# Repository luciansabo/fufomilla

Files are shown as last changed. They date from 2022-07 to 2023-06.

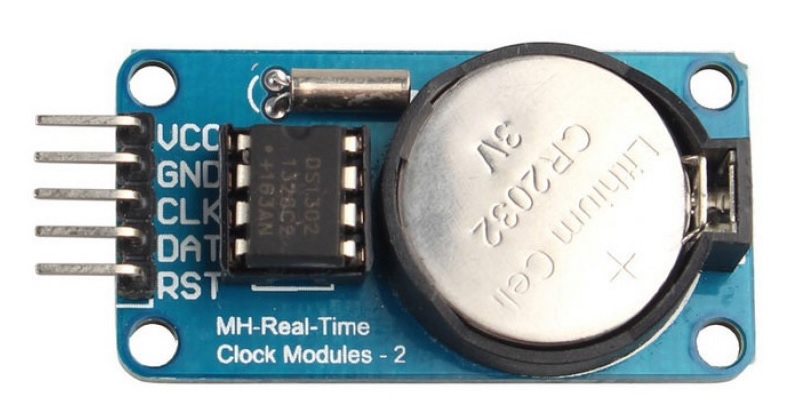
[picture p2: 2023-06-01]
docs/DS1302-RTC-mdule-pinout-diagram.jpg

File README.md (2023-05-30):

## Fufomilla

Automated Cat/Dog/Pet Feeder

*Created for ESP32/ESP32 CAM, but should work with minimal changes with other boards*

### Features
- based on a popular manual cereal dispenser + 3d printed parts 
- Wifi control/monitoring and automatic reconnects
- configuration portal (Wifi manager) on double reset
- supports ESP32 CAM (tested on the AI Thinker version) with 3 simultaneous camera streams and 20 fps, should work on any ESP32 though
- MQTT communication (can be easily integrated with Home Assistant) with integrated sensors like status, food level, remaining portions
- supports an optional ultrasonic food level sensor
- scheduled feeding based on NTP time and optionally a real time clock module
- manual feeding possible through MQTT a command

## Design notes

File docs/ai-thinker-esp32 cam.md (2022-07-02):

## INTRODUCTION TO AL-CAM THINKER

Source: https://www.electrorules.com/esp32-cam-ai-thinker-pinout-guide-gpios-usage-explained/

For quite some time, the world has revolved around IoTs, or Internet of Things. Everyone is interested in Smart technology, from enthusiasts to innovators, in building various prototypes and goods, and launching them on the market. One of the most common clever modules for IoTs is the ESP32 Series processor. Espressif’s ESP32-CAM AI-Thinker is an enhanced version of the ESP8266-01 with numerous functionalities. Two high-performance 32-bit LX6 CPUs with a 7-stage pipeline architecture are included in the ultra-small, low-power module.

## Applications
ESP32-CAM AI-Thinker module has a never-ending list of applications like home automation, intelligent devices, positioning systems, security systems and perfect for IoT applications.

## POWER PINS
The ESP32-CAM has three GND pins (coloured black) and two power pins (coloured red): 3.3V and 5V, respectively.

The ESP32-CAM can be powered from the 3.3V or 5V pins. However, many individuals have noticed issues while using 3.3V to power the ESP32-CAM, thus we always recommend using the 5V pin.

## POWER OUTPUT PIN
There’s also the VCC pin, which is labelled on the silkscreen (colored with a yellow rectangle). That pin should not be used to power the ESP32-CAM. That is a power output pin. It may produce either 5V or 3.3V.

Whether supplied with 5V or 3.3V, the ESP32-CAM outputs 3.3V in our situation. Two pads are located next to the VCC pin. One is labelled 3.3V and the other is labelled 5V.

## SERIAL PIN
GPIO 1 and GPIO 3 are the serial pins (TX and RX, respectively). Because the ESP32-CAM doesn’t have a built-in programmer, you need to use these pins to communicate with the board and upload code.

You can use GPIO 1 and GPIO 3 to connect other peripherals like outputs or sensors after uploading the code. However, you won’t be able to open the Serial Monitor and see if everything is going well with your setup.

GPIO 0
GPIO 0 determines whether the ESP32 is in flashing mode or not. This GPIO is internally connected to a pull-up 10k Ohm resistor.

When GPIO 0 is connected to GND, the ESP32 goes into flashing mode and you can upload code to the board.

GPIO 0 connected to GND » ESP32-CAM in flashing mode
To make the ESP32 run “normally”, you just need to disconnect GPIO 0 from GND.

## MICROSD CONNECTION
The following pins are used to interface with the microSD card when it is on operation.

Microsd card	ESP32
CLK	GPIO 14
CMD	GPIO15
DATA0	GPIO 2
DATA 1/flashlight	GPIO 4
DATA2	GPIO 12
DATA3	GPIO13

## FLASHLIGHT(GPIO4)
The ESP32-CAM has a very bright built-in LED that can work as a flash when taking

photos. That LED is internally connected to GPIO 4.

That GPIO is also connected to the microSD card slot, so you may have troubles when trying to use both at the same time – the flashlight will light up when using the microSD card.

## GPIO 33 – BUILT- IN RED LIGHT
An on-board red LED is located next to the RST button. Internally, its LED is coupled to GPIO 33. This LED can be used to signal that something is happening. When Wi-Fi is enabled, for example, the LED turns red, and vice versa.

That LED uses inverted logic, thus to turn it on, send a LOW signal, and to turn it off, provide a HIGH signal.

```
void setup() {

  pinMode(33, OUTPUT);

}

void loop() {

  digitalWrite(33, LOW);

}
```

## CAMERA CONNECTIONS
The connections between the camera and the ESP32-CAM AI-Thinker are shown in the following table.

OV2640 CAMERA	ESP32	Variable name in code
DO	GPIO 5	Y2_GPIO_NUM
D1	GPIO 18	Y3_GPIO_NUM
D2	GPIO 19	Y4_GPIO_NUM
D3	GPIO 21	Y5_GPIO_NUM
D4	GPIO 36	Y6_GPIO_NUM
D5	GPIO 39	Y7_GPIO_NUM
D6	GPIO 34	Y8_GPIO_NUM
D7	GPIO 35	Y9_GPIO_NUM
XCLK	GPIO 0	XCLK_GPIO_NUM
PCLK	GPIO 22	PCLK_GPIO_NUM
VSYNC	GPIO 25	VSYNC_GPIO_NUM
HREF	GPIO 23	HREF_GPIO_NUM
SDA	GPIO 26	SIOD_GPIO_NUM
SCL	GPIO 27	SIOC_GPIO_NUM
POWERPIN	GPIO 32	PWDN_GPIO_NUM

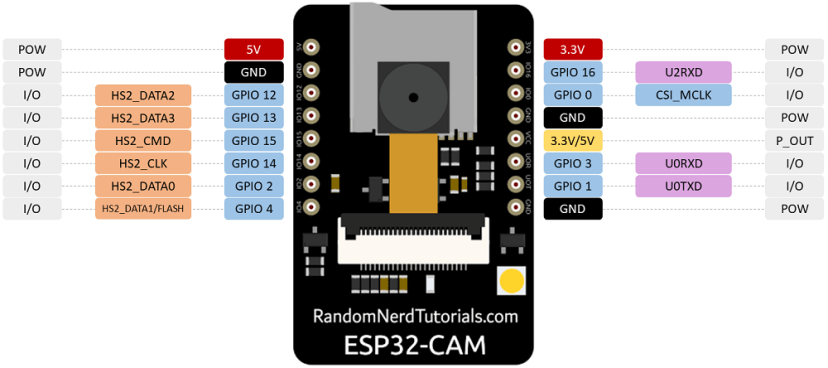
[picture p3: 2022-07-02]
docs/ESP32-CAM-pinout.png

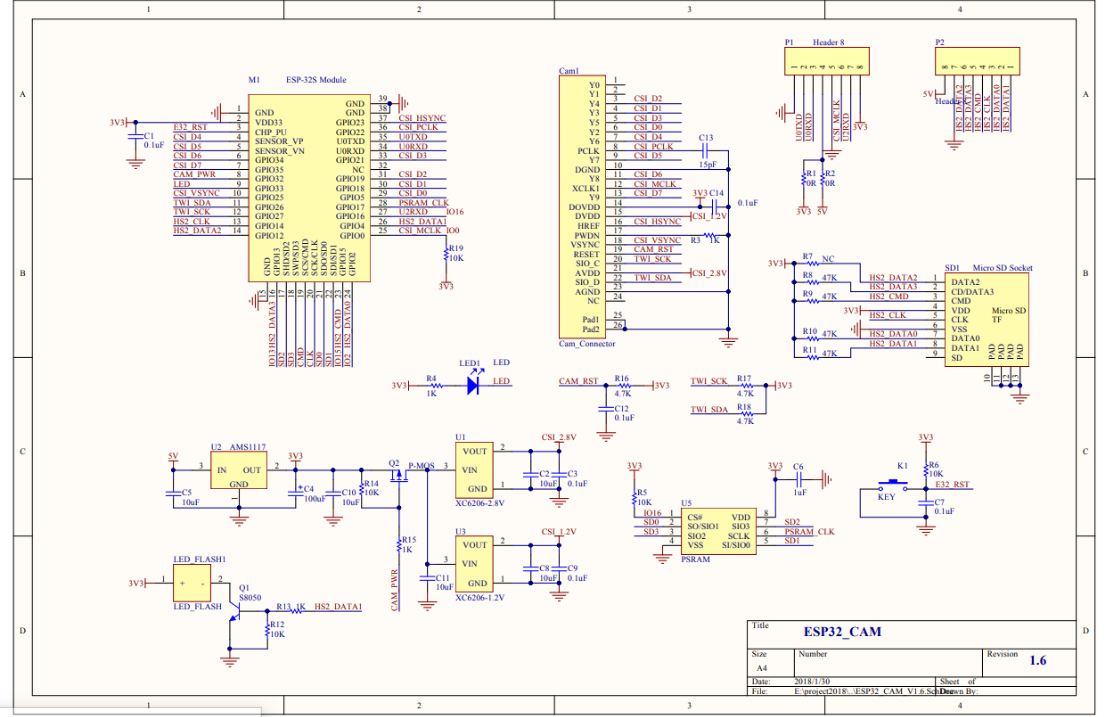
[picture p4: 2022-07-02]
docs/ESP32-CAM-circuit-diagram.PNG

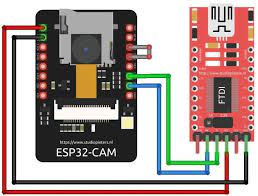
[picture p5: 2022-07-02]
docs/ftdi-connections.jpeg

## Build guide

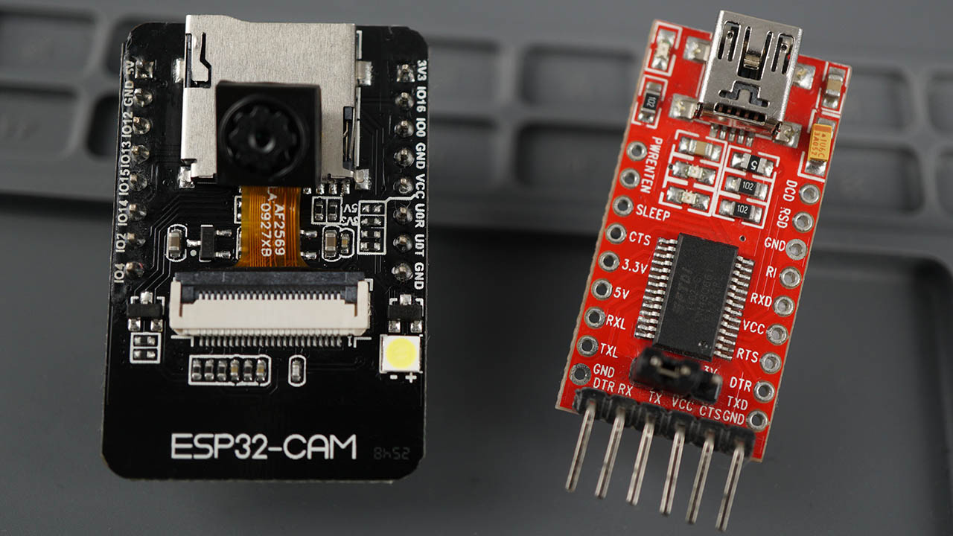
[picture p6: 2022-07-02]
docs/how-to-program-upload-code-firmware-ESP32-CAM-board-Arduino-IDE-FTDI.jpg

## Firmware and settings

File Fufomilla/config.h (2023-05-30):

#define HAS_FOOD_LEVEL_SENSOR 1
#define HAS_RTC               1
#define HAS_CAMERA            1

// Pins
#define PIN_SERVO 13
#define PIN_BRIGHT_LED 4
#define PIN_BUILTIN_LED 33

#define PIN_RTC_DAT        2
#define PIN_RTC_CLK       16
#define PIN_RTC_RST       12

#define PIN_HCSR04_TRIG 14
#define PIN_HCSR04_ECHO 15


// Timing
#define DEFAULT_JERK_TIME 1 * 1000 // controls portion. Time in ms to rotate left/right
#define WIFI_WATCHDOG_INTERVAL  (5 * 60 * 1000) // 5m
#define MQTT_WATCHDOG_INTERVAL  (60 * 1000) // 1m
#define MQTT_HANDLING_INTERVAL  (1 * 1000) // 1s
#define MQTT_KEEP_ALIVE_SEC     60 // 60s
#define FOOD_LEVEL_READING_INTERVAL (3600 * 1000) // 1h
#define RTC_SYNC_INTERVAL_WITH_NTC (4 * 60 * 1000) // every 4h

// Config portal
#define CONFIG_PORTAL_AP_NAME   "Fufomilla"
#define CONFIG_PORTAL_AP_PASS   ""
#define CONFIG_PORTAL_TIMEOUT_SEC (10 * 60) // 10 min

// wifi
#define HOSTNAME                "Fufomilla"
#define WIFI_CONNECT_TIMEOUT_SEC 40 // 40s

// Number of seconds after reset during which a
// subseqent reset will be considered a double reset.
#define DRD_TIMEOUT 10

// RTC Memory Address for the DoubleResetDetector to use
#define DRD_ADDRESS 0

// ID of the settings block
#define CONFIG_VERSION "FM1"

// Tell it where to store your config data in EEPROM
#define CONFIG_START_ADDR 0

// Time
#define TIME_TZ                "EET-2EEST,M3.5.0/3,M10.5.0/4"
#define TIME_NTP_SERVER        "pool.ntp.org"

// MQTT
#define DEFAULT_MQTT_BROKER   "home-assistant.local"
#define DEFAULT_MQTT_PORT     "1883"
#define DEFAULT_MQTT_USERNAME "homeassistant"
#define DEFAULT_MQTT_PASSWORD ""
#define TOPIC_COMMAND_FEED_ME "saboiot/fufomilla/commands/feed"
#define TOPIC_COMMAND_SWITCH_LED      "saboiot/fufomilla/commands/led"
#define TOPIC_EVENTS          "saboiot/fufomilla/events"
#define TOPIC_FOOD_LEVEL      "saboiot/fufomilla/food-level"
#define TOPIC_LED    "saboiot/fufomilla/led"
#define TOPIC_AVAILABILITY    "saboiot/fufomilla/availability"

#define FOOD_CONTAINER_HEIGHT_CM 20
#define FOOD_CONTAINER_PORTIONS 36

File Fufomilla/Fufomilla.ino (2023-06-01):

/*
   Fufomilla - cat feeder
   Board: ESP32 Dev module
   Minimal SPIFFS
   PSRAM Disabled -> incompatible with DS1302 RTC module
   Arduino run on Core 1, events on Core 0
*/

#include <ESP32Servo.h>
#include <WiFiManager.h>
#include <PubSubClient.h>  // MQTT Client
#include <ArduinoOTA.h>
#include <ESPmDNS.h>
#include <time.h>
#include <CronAlarms.h>
#include <SimpleTimer.h>  // https://playground.arduino.cc/Code/SimpleTimer/

// ESP32 needs EEPROM
#if defined(ESP32)
#define USE_SPIFFS true
#define ESP_DRD_USE_EEPROM true
#else
#error This code is intended to run on the ESP32 platform! Please check your Tools->Board setting.
#endif
#include <ESP_DoubleResetDetector.h>  //https://github.com/khoih-prog/ESP_DoubleResetDetector

// app config
#include "config.h"
#include "config.local.h"

#ifdef HAS_FOOD_LEVEL_SENSOR
#include <HCSR04.h>
UltraSonicDistanceSensor distanceSensor(PIN_HCSR04_TRIG, PIN_HCSR04_ECHO);
#endif

#ifdef HAS_RTC
#include <ThreeWire.h>
#include <RtcDS1302.h>

ThreeWire threeWire(PIN_RTC_DAT, PIN_RTC_CLK, PIN_RTC_RST);  // IO, SCLK, CE
RtcDS1302<ThreeWire> rtc(threeWire);
#endif

DoubleResetDetector* drd;

// network
WiFiClient espClient;
unsigned long wifiReconnectTime = 0;
// servers
PubSubClient mqtt(espClient);

bool isManualDispense = false;

#ifdef HAS_CAMERA
#include "Esp32CamAsyncWebserver.h"
camera_config_t esp32cam_aithinker_config{

  .pin_pwdn = 32,
  .pin_reset = -1,

  .pin_xclk = 0,

  .pin_sscb_sda = 26,
  .pin_sscb_scl = 27,

  // Note: LED GPIO is apparently 4 not sure where that goes
  // per https://github.com/donny681/ESP32_CAMERA_QR/blob/e4ef44549876457cd841f33a0892c82a71f35358/main/led.c
  .pin_d7 = 35,
  .pin_d6 = 34,
  .pin_d5 = 39,
  .pin_d4 = 36,
  .pin_d3 = 21,
  .pin_d2 = 19,
  .pin_d1 = 18,
  .pin_d0 = 5,
  .pin_vsync = 25,
  .pin_href = 23,
  .pin_pclk = 22,
  .xclk_freq_hz = 20000000,  // faster fps
  .ledc_timer = LEDC_TIMER_1,
  .ledc_channel = LEDC_CHANNEL_1,
  .pixel_format = PIXFORMAT_JPEG,
  // .frame_size = FRAMESIZE_UXGA, // needs 234K of framebuffer space
  // .frame_size = FRAMESIZE_SXGA, // needs 160K for framebuffer
  // .frame_size = FRAMESIZE_XGA, // needs 96K or even smaller FRAMESIZE_SVGA - can work if using only 1 fb
  .frame_size = FRAMESIZE_QVGA,      // 240x176
  .jpeg_quality = 15,                //0-63 lower numbers are higher quality
  .fb_count = 1,                     // if more than one i2s runs in continous mode.  Use only with jpeg
  .fb_location = CAMERA_FB_IN_DRAM,  // disable PSRAM
  .grab_mode = CAMERA_GRAB_WHEN_EMPTY
};

Esp32CamWebserver camServer;
#endif

// software timer
SimpleTimer simpleTimer;

// MQTT Broker
struct MqttConfigStruct {
  char configVersion[5] = CONFIG_VERSION;
  char broker[100] = DEFAULT_MQTT_BROKER;
  char port[5] = DEFAULT_MQTT_PORT;
  char username[30] = DEFAULT_MQTT_USERNAME;
  char password[100] = DEFAULT_MQTT_PASSWORD;
  uint16_t jerkTime = DEFAULT_JERK_TIME;
} mqttConfig;

// Wifimanager variables
WiFiManager wifiManager;
WiFiManagerParameter paramMqttBroker("mqttBroker", "MQTT broker", mqttConfig.broker, 40);
WiFiManagerParameter paramMqttPort("mqttPort", "MQTT port", mqttConfig.port, 10);
WiFiManagerParameter paramMqttUsername("mqttUser", "MQTT user", mqttConfig.username, 40);
WiFiManagerParameter paramMqttPassword("mqttPassword", "MQTT password", mqttConfig.password, 40);

Servo myservo;  // create servo object to control a servo
// 16 servo objects can be created on the ESP32

struct TStats {
  time_t upSince;
  char lastOperation[100];
} stats;

// ------------------------------------------------------------------------------------------

void setupOTA() {
  ArduinoOTA.setHostname(HOSTNAME);
  ArduinoOTA.begin();
  ArduinoOTA.onStart([]() {
    log_i("OTA firmware update started");
    //hwTimer.disableTimer();
  });
  ArduinoOTA.onEnd([]() {
    log_i("OTA Updated completed");
    // hwTimer.enableTimer();
  });
  ArduinoOTA.onError([](ota_error_t error) {
    //hwTimer.enableTimer();
    log_e("Error[%u]: ", error);
    if (error == OTA_AUTH_ERROR) {
      log_e("Auth Failed");
    } else if (error == OTA_BEGIN_ERROR) {
      log_e("Begin Failed");
    } else if (error == OTA_CONNECT_ERROR) {
      log_e("Connect Failed");
    } else if (error == OTA_RECEIVE_ERROR) {
      log_e("Receive Failed");
    } else if (error == OTA_END_ERROR) {
      log_e("End Failed");
    }
  });
}

// ------------------------------------------------------------------------------------------


void mqttPublish(const char* topic, const char* message, bool retain = false) {
  ensureMqttConnected();

  if (!mqtt.publish(topic, message, retain)) {
    log_e("MQTT Publish failed. Topic: %s\nMsg: %s\nState: %d", topic, message, mqtt.state());
  }
}

// ------------------------------------------------------------------------------------------

void ensureMqttConnected() {
  if (WiFi.status() != WL_CONNECTED) {
    return;
  }

  if (mqtt.connected()) {
    return;
  }

  log_i("Connecting to the mqtt broker... ");

  if (mqtt.connect(HOSTNAME, mqttConfig.username, mqttConfig.password, TOPIC_AVAILABILITY, 0, true, "{\"status\": \"offline\", \"upSince\": null}")) {
    log_i("Connected to MQTT");
    mqtt.subscribe(TOPIC_COMMAND_FEED_ME);
    mqtt.subscribe(TOPIC_COMMAND_SWITCH_LED);

    char message[200];
    //char timeBuf[sizeof "2011-10-08T07:07:09Z"];
    //strftime(timeBuf, sizeof timeBuf, "%FT%TZ", localtime(&stats.upSince));
    char timeBuf[sizeof "Joi, 30 Aug 2022 09:03"];
    strftime(timeBuf, sizeof timeBuf, "%a, %e %b %Y %R", localtime(&stats.upSince));
    sprintf(message, "{\"status\": \"online\",  \"upSince\": \"%s\"}", timeBuf);
    log_i("Publish availability message: %s", message);
    mqttPublish(TOPIC_AVAILABILITY, message, true);
  } else {
    log_e("failed with state %d", mqtt.state());
  }
}

// ------------------------------------------------------------------------------------------

void _dispenseMinPortion() {
  // try to fix issue with bright led that lits up
  digitalWrite(PIN_BRIGHT_LED, LOW);
  myservo.write(180);
  delay(DEFAULT_JERK_TIME);
  myservo.write(90);
  delay(200);
  myservo.write(0);
  delay(DEFAULT_JERK_TIME);
  myservo.write(90);
  digitalWrite(PIN_BRIGHT_LED, LOW);
}

// ------------------------------------------------------------------------------------------
/*void onDispenseStart() {
  
}*/

// ------------------------------------------------------------------------------------------

void onDispenseCompleted() {
  char message[200];
  char timeBuf[sizeof "Joi, 30 Aug 2022 09:03"];
  struct tm timeinfo;

  getLocalTime(&timeinfo);

  strftime(timeBuf, sizeof timeBuf, "%R %e %b", &timeinfo);
  sprintf(message, "{\"event\": \"%s %s\"}",
          isManualDispense ? "Manual feeding at" : "Scheduled feeding at",
          timeBuf);
  mqttPublish(TOPIC_EVENTS, message, true);

#ifdef HAS_FOOD_LEVEL_SENSOR
  readFoodLevel();
#endif
}

// ------------------------------------------------------------------------------------------

void dispense() {
  //onDispenseStart();
  log_i("Scheduled dispense");
  _dispenseMinPortion();
  onDispenseCompleted();
}

// ------------------------------------------------------------------------------------------

void manualDispense() {
  //onDispenseStart();
  log_i("Manually Dispensing");
  isManualDispense = true;
  _dispenseMinPortion();

  onDispenseCompleted();
  isManualDispense = false;
}

// ------------------------------------------------------------------------------------------

void publishNightLedStatus() {
  char message[100];
  sprintf(message, "{\"status\": \"%s\"}",
          digitalRead(PIN_BRIGHT_LED) ? "ON" : "OFF");

  mqttPublish(TOPIC_LED, message, true);
}

// ------------------------------------------------------------------------------------------

void turnLedOn() {
  digitalWrite(PIN_BRIGHT_LED, HIGH);
  publishNightLedStatus();
}

// ------------------------------------------------------------------------------------------

void turnLedOff() {
  digitalWrite(PIN_BRIGHT_LED, LOW);
  publishNightLedStatus();
}


// ------------------------------------------------------------------------------------------

void mqttCallback(char* topic, byte* payload, unsigned int length) {
  log_i("Message arrived on topic: %s", topic);

  if (String(topic) == TOPIC_COMMAND_FEED_ME) {
    manualDispense();
  } else if (String(topic) == TOPIC_COMMAND_SWITCH_LED) {
    char message[100];
    strncpy(message, (char*)payload, length);

    if (strcmp(message, "ON") == 0) {
      turnLedOn();
    } else {
      turnLedOff();
    }
  }
}

// ------------------------------------------------------------------------------------------

void WiFiStationConnected(WiFiEvent_t event, WiFiEventInfo_t info) {
  log_i("Connected to AP successfully");
  wifiReconnectTime = 0;
}

// ------------------------------------------------------------------------------------------

void WiFiGotIP(WiFiEvent_t event, WiFiEventInfo_t info) {
  log_i("WiFi connected. IP address: %s", WiFi.localIP().toString().c_str());
  ensureMqttConnected();
}

// ------------------------------------------------------------------------------------------

void wifiReconnect() {
  log_i("Trying to Reconnect to Wifi");
  WiFi.disconnect();
  Cron.delay(5000);
  WiFi.reconnect();
}
// ------------------------------------------------------------------------------------------

void WiFiStationDisconnected(WiFiEvent_t event, WiFiEventInfo_t info) {
  if (millis() - wifiReconnectTime > 20 * 1000) {
    return;
  }

  log_w("WiFi lost connection.\n");
  wifiReconnectTime = millis();
  wifiReconnect();
}

// ------------------------------------------------------------------------------------------

void wifiWatchdog() {
  if (WiFi.status() != WL_CONNECTED) {
    wifiReconnectTime = millis();
    wifiReconnect();
  }
}

// ------------------------------------------------------------------------------------------
void publishMQTTDiscoveryMessages() {
  char message[512];
  char availText[200];
  snprintf(availText, sizeof(availText), "\"avty_t\": \"%s\", \"avty_tpl\": \"{{ value_json.status }}\"", TOPIC_AVAILABILITY);

  // Feed me command
  snprintf(message, sizeof(message), "{\"name\": \"Fufomilla Feed Me\", %s, \"cmd_t\": \"%s\", \"frc_upd\": true }",
           availText,
           TOPIC_COMMAND_FEED_ME);
  mqttPublish("homeassistant/button/fufomilla/feedMe/config", message, true);

  // Switch Night Vision LED command
  snprintf(message, sizeof(message), "{\"name\": \"Fufomilla night vision LED\", %s, \"dev_cla\": \"switch\", \"cmd_t\": \"%s\", \"stat_t\": \"%s\", \"val_tpl\": \"{{ value_json.status}}\", \"frc_upd\": true }",
           availText,
           TOPIC_COMMAND_SWITCH_LED,
           TOPIC_LED);
  mqttPublish("homeassistant/switch/fufomilla/led/config", message, true);


#ifdef HAS_FOOD_LEVEL_SENSOR
  // Food Level percentage
  snprintf(message, sizeof(message), "{\"name\": \"Fufomilla Food Level\", \"stat_t\": \"%s\", \"unit_of_meas\": \"%%\", \
    %s, \"val_tpl\": \"{{ value_json.level}}\", \"frc_upd\": true }",
           TOPIC_FOOD_LEVEL,
           availText);
  mqttPublish("homeassistant/sensor/fufomilla/foodLevel/config", message, true);

  // Food level - remaining portions
  snprintf(message, sizeof(message), "{\"name\": \"Fufomilla Remaining Portions\", \"stat_t\": \"%s\", %s, \
    \"val_tpl\": \"{{ value_json.remainingPortions}}\", \"frc_upd\": true }",
           TOPIC_FOOD_LEVEL,
           availText);
  mqttPublish("homeassistant/sensor/fufomilla/remainingPortions/config", message, true);
#endif

  // Last event
  sprintf(message, "{\"name\": \"Fufomilla Last event\", \"stat_t\": \"%s\", \
    \"val_tpl\": \"{{ value_json.event}}\", \"frc_upd\": true }",
          TOPIC_EVENTS);
  mqttPublish("homeassistant/sensor/fufomilla/lastEvent/config", message, true);

  // Up since
  sprintf(message, "{\"name\": \"Fufomilla up since\", \"stat_t\": \"%s\", \
    \"val_tpl\": \"{{ value_json.upSince}}\", \"frc_upd\": true }",
          TOPIC_AVAILABILITY);
  mqttPublish("homeassistant/sensor/fufomilla/upSince/config", message, true);
}

// ------------------------------------------------------------------------------------------
#ifdef HAS_RTC
void setupRTC() {
  rtc.Begin();

  if (!rtc.IsDateTimeValid()) {
    // Common Causes:
    //    1) first time you ran and the device wasn't running yet
    //    2) the battery on the device is low or even missing

    log_w("RTC lost confidence in the DateTime!");
    rtc.SetDateTime(RtcDateTime(__DATE__, __TIME__));
  }

  if (rtc.GetIsWriteProtected()) {
    log_w("RTC was write protected, enabling writing now");
    rtc.SetIsWriteProtected(false);
  }

  if (!rtc.GetIsRunning()) {
    log_w("RTC was not actively running, starting now");
    rtc.SetIsRunning(true);
  }
}
#endif
// ------------------------------------------------------------------------------------------

#ifdef HAS_FOOD_LEVEL_SENSOR
void readFoodLevel() {
  char message[200];
  int distance = distanceSensor.measureDistanceCm();
  log_i("Read food level distance: %d cm", distance);
  if (distance <= 0) {
    return;
  }


  if (distance > FOOD_CONTAINER_HEIGHT_CM) {
    distance = FOOD_CONTAINER_HEIGHT_CM;
  }

  uint8_t level = 100 - ((distance * 100) / FOOD_CONTAINER_HEIGHT_CM);

  sprintf(message, "{\"level\": %d, \"remainingPortions\": %d}",
          level,
          (level * FOOD_CONTAINER_PORTIONS) / 100);

  mqttPublish(TOPIC_FOOD_LEVEL, message, true);
}
#endif


// ------------------------------------------------------------------------------------------

void doWiFiManager() {
  // is configuration portal requested?

  if (drd->detectDoubleReset()) {
    log_i("Starting Config Portal");
    // important - disable webserver to be able to use the config portal routes
    camServer.disable();
    wifiManager.setEnableConfigPortal(true);
    wifiManager.startConfigPortal(CONFIG_PORTAL_AP_NAME, CONFIG_PORTAL_AP_PASS);
    wifiManager.setEnableConfigPortal(false);
    camServer.enable();
  }
}

// ------------------------------------------------------------------------------------------


void setup() {

  log_i("Fufomilla Feeder is starting");

  pinMode(PIN_BRIGHT_LED, OUTPUT);
  digitalWrite(PIN_BRIGHT_LED, LOW);
  drd = new DoubleResetDetector(DRD_TIMEOUT, DRD_ADDRESS);
  doWiFiManager();

#ifdef HAS_RTC
  log_i("Initialize RTC module");
  setupRTC();
  RtcDateTime now = rtc.GetDateTime();
  if (now.IsValid()) {
    char datestring[20];

    snprintf_P(datestring,
               sizeof(datestring),
               PSTR("%02u/%02u/%04u %02u:%02u:%02u"),
               now.Month(),
               now.Day(),
               now.Year(),
               now.Hour(),
               now.Minute(),
               now.Second());

    log_i("RTC time: %s", datestring);

    struct timeval cTimeNow;
    cTimeNow.tv_sec = now.Epoch64Time();
    settimeofday(&cTimeNow, NULL);
  } else {
    log_w("Invalid RTC time");
  }
#endif

  WiFi.mode(WIFI_STA);  // explicitly set mode, esp defaults to STA+AP

  // Allow allocation of all timers
  ESP32PWM::allocateTimer(0);
  ESP32PWM::allocateTimer(1);
  ESP32PWM::allocateTimer(2);
  ESP32PWM::allocateTimer(3);
  myservo.setPeriodHertz(50);  // standard 50 hz servo
  // using default min/max of 1000us and 2000us
  myservo.attach(PIN_SERVO, 1000, 2000);

  wifiManager.setHostname(HOSTNAME);
  wifiManager.setWiFiAutoReconnect(true);
  wifiManager.setConnectTimeout(WIFI_CONNECT_TIMEOUT_SEC);
  wifiManager.setConnectRetries(10);
  wifiManager.setDebugOutput(false);
  wifiManager.setEnableConfigPortal(false);
  wifiManager.setConfigPortalBlocking(true);
  wifiManager.setConfigPortalTimeout(CONFIG_PORTAL_TIMEOUT_SEC);
  //wifiManager.setSaveConfigCallback(saveConfigCallback);
  wifiManager.setBreakAfterConfig(true);  // call save callback even if empty wifi or failed
  // custom params
  wifiManager.addParameter(&paramMqttBroker);
  wifiManager.addParameter(&paramMqttPort);
  wifiManager.addParameter(&paramMqttUsername);
  wifiManager.addParameter(&paramMqttPassword);
  log_i("Connecting to Wifi...");
  wifiManager.autoConnect();

  log_i("Trying to sync time with NTP");
  // must be before logging starts
  configTzTime(TIME_TZ, TIME_NTP_SERVER);

  struct tm timeinfo;
  getLocalTime(&timeinfo);

  // wait until we have acquired the time
  while (!getLocalTime(&timeinfo)) {
    delay(100);
  }
  log_i("Successfully aquired time using NTP: %s", asctime(&timeinfo));

  stats.upSince = mktime(&timeinfo);

  mqtt.setServer(mqttConfig.broker, atoi(mqttConfig.port));
  mqtt.setKeepAlive(MQTT_KEEP_ALIVE_SEC);
  mqtt.setCallback(mqttCallback);
  mqtt.setBufferSize(512);  // increase/double buffer size so larger messages can be sent without reallocation
  ensureMqttConnected();

  WiFi.onEvent(WiFiStationConnected, WiFiEvent_t::ARDUINO_EVENT_WIFI_STA_CONNECTED);
  WiFi.onEvent(WiFiGotIP, WiFiEvent_t::ARDUINO_EVENT_WIFI_STA_GOT_IP);
  WiFi.onEvent(WiFiStationDisconnected, WiFiEvent_t::ARDUINO_EVENT_WIFI_STA_DISCONNECTED);

  setupOTA();

  simpleTimer.setInterval(WIFI_WATCHDOG_INTERVAL, wifiWatchdog);
  simpleTimer.setInterval(MQTT_WATCHDOG_INTERVAL, ensureMqttConnected);
  simpleTimer.setInterval(MQTT_HANDLING_INTERVAL, []() {
    mqtt.loop();
  });

  // setup feeeding schedule
  Cron.create((char*)"0 0 7 * * *", dispense, false);   // 07:00 each day
  Cron.create((char*)"0 0 19 * * *", dispense, false);  // 19:00 each day

  publishMQTTDiscoveryMessages();

#ifdef HAS_FOOD_LEVEL_SENSOR
  simpleTimer.setTimeout(FOOD_LEVEL_READING_INTERVAL, readFoodLevel);
  readFoodLevel();
#endif

  publishNightLedStatus();

#ifdef HAS_RTC
  simpleTimer.setInterval(RTC_SYNC_INTERVAL_WITH_NTC, []() {
    log_i("Sync RTC module with NTP time");
    // adjust RTC time from NTP
    RtcDateTime utc;
    utc.InitWithEpoch64Time(time(NULL));
    rtc.SetDateTime(utc);
    RtcDateTime now = rtc.GetDateTime();
  });
#endif

#ifdef HAS_CAMERA
  log_i("Initialize camera server");
  camServer.start(esp32cam_aithinker_config);
#endif

  log_i("Initialize MDNS");
  if (!MDNS.begin(HOSTNAME)) {
    log_e("Error encountered while starting mDNS");
  }
}

// ------------------------------------------------------------------------------------------

void loop() {
  ArduinoOTA.handle();
  simpleTimer.run();
  Cron.delay(0);

#ifdef HAS_CAMERA
  camServer.run();
#endif

  // Call the double reset detector loop method every so often,
  // so that it can recognise when the timeout expires.
  // You can also call drd.stop() when you wish to no longer
  // consider the next reset as a double reset.
  drd->loop();
}

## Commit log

2023-05-30 improved camera, support 3 simultaneous streams, use esp32 logging
2023-06-01 reformatted code
    [fritzing-sketck.fzz]
